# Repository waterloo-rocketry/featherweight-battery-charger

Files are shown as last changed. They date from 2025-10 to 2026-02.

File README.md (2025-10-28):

# featherweight-battery-charger

- add grounds
- when your chip suddenly draws a lot of power, it gets a big change in current which is a problem: in those moments, voltage is irregular. so the point of decoupling capacitor is to store charge
- in general, depends on pin/chip, datasheet will give recommended or calculate it yourself :(
- change resistor value (?)
- buck converter -> 12v to 5v (do this cuz it's step down standard), we probably need to design it (we gotta buy buck converter ic maybe check with ash)

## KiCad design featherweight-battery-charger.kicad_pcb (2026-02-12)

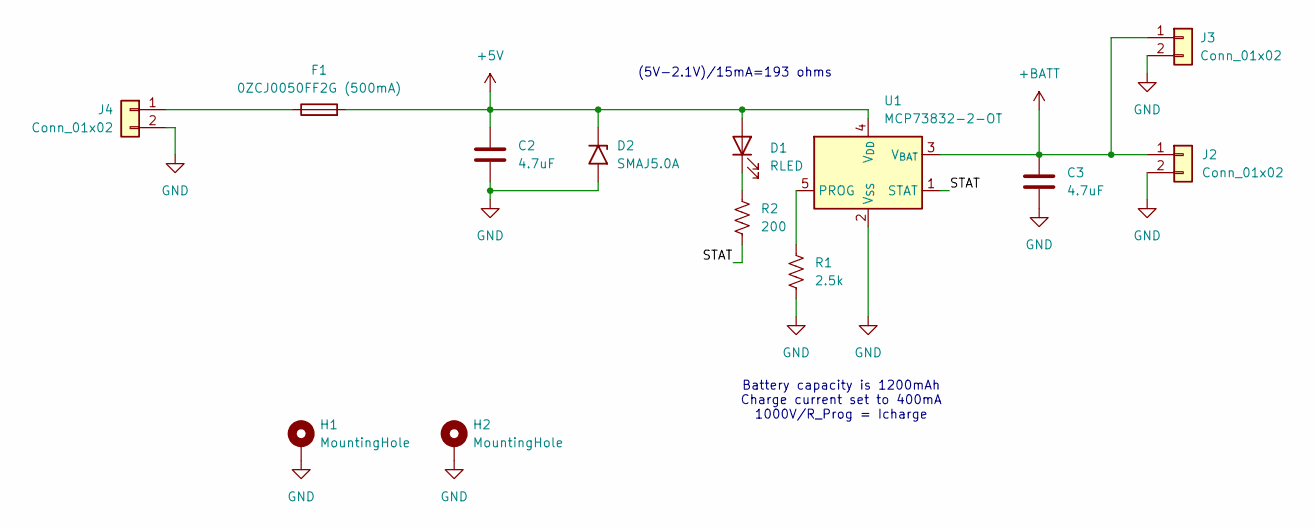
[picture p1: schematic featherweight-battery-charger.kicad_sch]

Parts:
C2, C3: 4.7uF; C_0603_1608Metric_Pad1.08x0.95mm_HandSolder
D1: RLED; LED_1206_3216Metric_Pad1.42x1.75mm_HandSolder
D2: SMAJ5.0A; D_SMA
F1: 0ZCJ0050FF2G (500mA); Fuse_1206_3216Metric_Pad1.42x1.75mm_HandSolder
H1, H2: MountingHole; MountingHole_3.2mm_M3_Pad
J2, J3: Conn_01x02; JST_PH_S2B-PH-K_1x02_P2.00mm_Horizontal
J4: Conn_01x02; JST_VH_S2P-VH_1x02_P3.96mm_Horizontal
R1: 2.5k; R_0603_1608Metric_Pad0.98x0.95mm_HandSolder
R2: 200; R_0603_1608Metric_Pad0.98x0.95mm_HandSolder
U1: MCP73832-2-OT; SOT-23-5

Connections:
+5V: C2.1, D1.2 (A), D2.1 (A1), F1.2, U1.4 (V_{DD})
+BATT: C3.1, J2.1, J3.1, U1.3 (V_{BAT})
/STAT: R2.2, U1.1 (STAT)
GND: C2.2, C3.2, D2.2 (A2), H1.1, H2.1, J2.2, J3.2, J4.2, R1.2, U1.2 (V_{SS})
unnamed: D1.1 (K), R2.1
unnamed: F1.1, J4.1
unnamed: R1.1, U1.5 (PROG)

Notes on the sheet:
Battery capacity is 1200mAh Charge current set to 400mA 1000V/R_Prog = Icharge
(5V-2.1V)/15mA=193 ohms

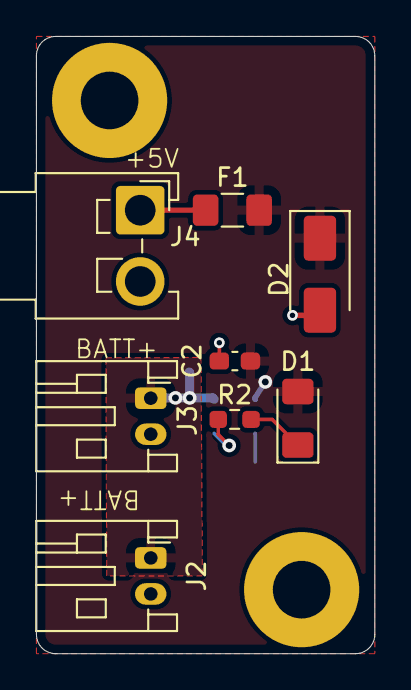
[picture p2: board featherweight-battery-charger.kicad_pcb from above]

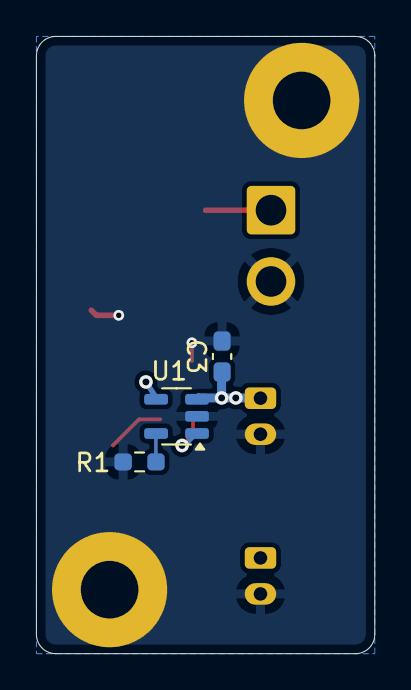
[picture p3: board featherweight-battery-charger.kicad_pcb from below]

Board: 2 copper layers, 18.8 x 34.3 mm, 13 parts (3 on the bottom side), 7 nets.

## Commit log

2025-10-27 page setup and team footprints
    [featherweight-battery-charger.kicad_sch]
2025-10-28 Added components + general layout
    [featherweight-battery-charger.kicad_sch]
2025-11-02 updated schematic
    [featherweight-battery-charger.kicad_sch]
2025-11-08 buck converter without values
    [featherweight-battery-charger.kicad_sch]
2025-11-08 Changed resistor icon in schematic
2025-11-24 finished buck converter part
    [featherweight-battery-charger.kicad_sch]
2025-12-01 Added resistor values
    [featherweight-battery-charger.kicad_sch]
2026-01-07 Changed Buck, Added Connectors and Fuse
    [featherweight-battery-charger.kicad_sch]
2026-01-07 To create a diff between PR and main
    [featherweight-battery-charger.kicad_sch]
2026-01-09 Added New Buck and Kicad Footprints Submodule
    [featherweight-battery-charger.kicad_pcb, featherweight-battery-charger.kicad_sch]
2026-01-09 Started Layout and Routing
    [featherweight-battery-charger.kicad_pcb, featherweight-battery-charger.kicad_sch]
2026-01-10 Did most of the layout and routing, need to finish silkscreen and then check everything
    [featherweight-battery-charger.kicad_pcb, featherweight-battery-charger.kicad_sch]
2026-01-10 Fixed some routing and silkscreen, should be done hopefully
    [featherweight-battery-charger.kicad_pcb]
2026-01-10 Forgot the schematic changes
    [featherweight-battery-charger.kicad_sch]
2026-01-11 Changed Layout and Routing
    [featherweight-battery-charger.kicad_pcb, featherweight-battery-charger.kicad_sch]
2026-01-11 Fixed up Silkscreen
    [featherweight-battery-charger.kicad_pcb]
2026-01-16 Remove seemingly pointless via
    [featherweight-battery-charger.kicad_pcb]
2026-01-16 Change C2 from 1uF to 4.7uF
    [featherweight-battery-charger.kicad_pcb, featherweight-battery-charger.kicad_sch]
2026-01-22 Fixed Dimensions to Line Holes up with Featherweight
    [featherweight-battery-charger.kicad_pcb]
2026-01-22 Changed Layout and Routing, Added Calculation Comments and Batt plane for heat diff. Fuse changed to 1206
    [featherweight-battery-charger.kicad_pcb, featherweight-battery-charger.kicad_sch]
